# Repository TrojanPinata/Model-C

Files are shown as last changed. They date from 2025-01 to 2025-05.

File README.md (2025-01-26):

<div align="center">

# Model-C

### A four function calculator and numpad combo with integrated battery, power-saving, and mechanical switches

The first version of this project is stored in the `old pcb` directory, and is based off of the ATmega32A MCU. While good, I felt like the RP2040 is more realistic in terms of both cost and development overhead.

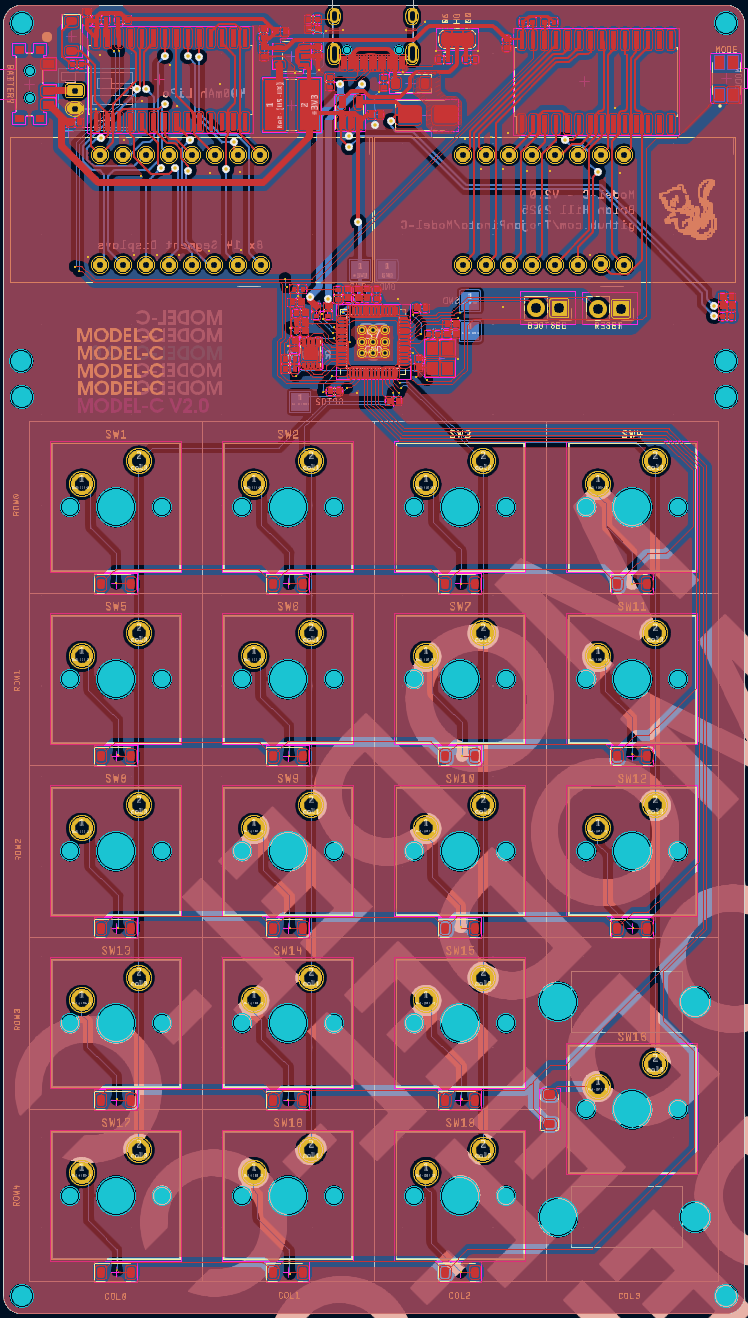
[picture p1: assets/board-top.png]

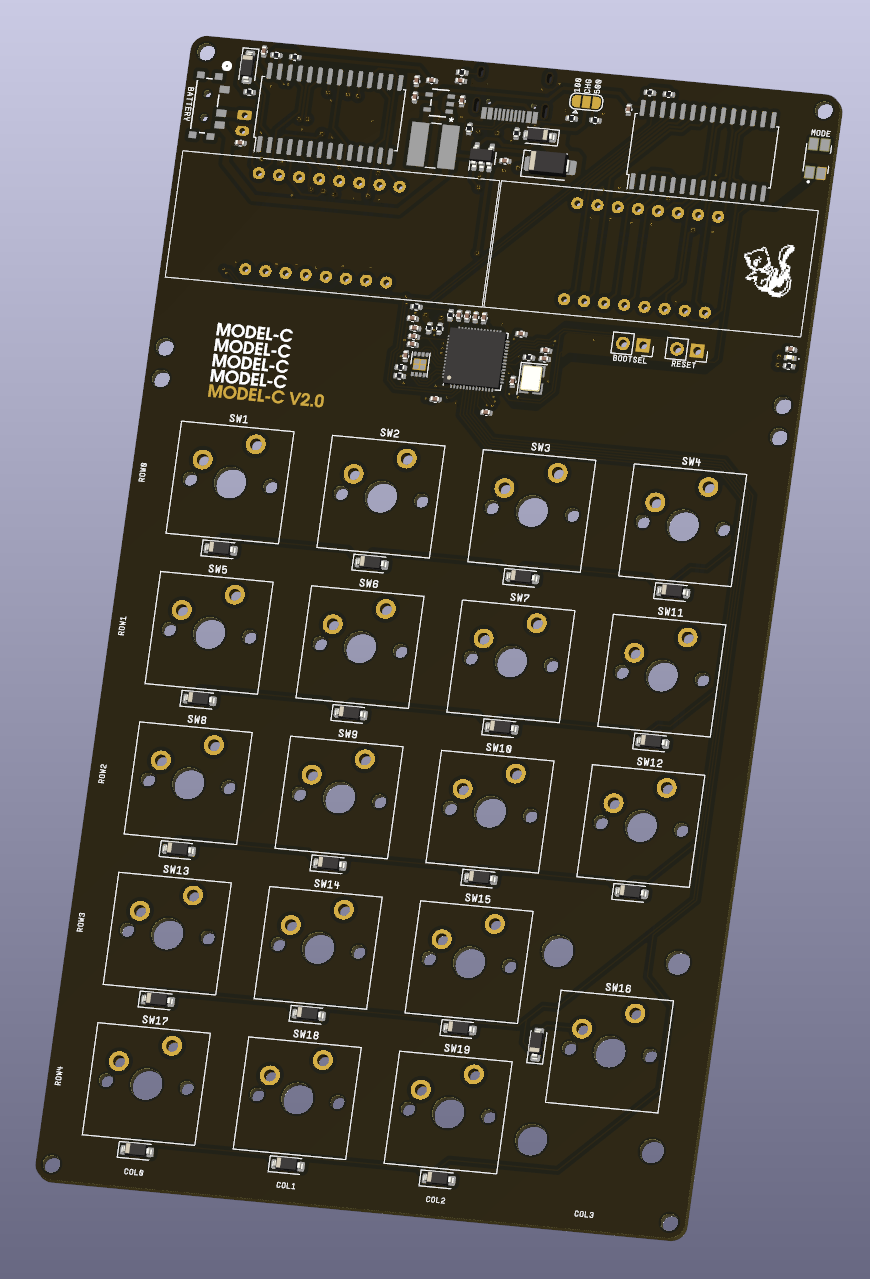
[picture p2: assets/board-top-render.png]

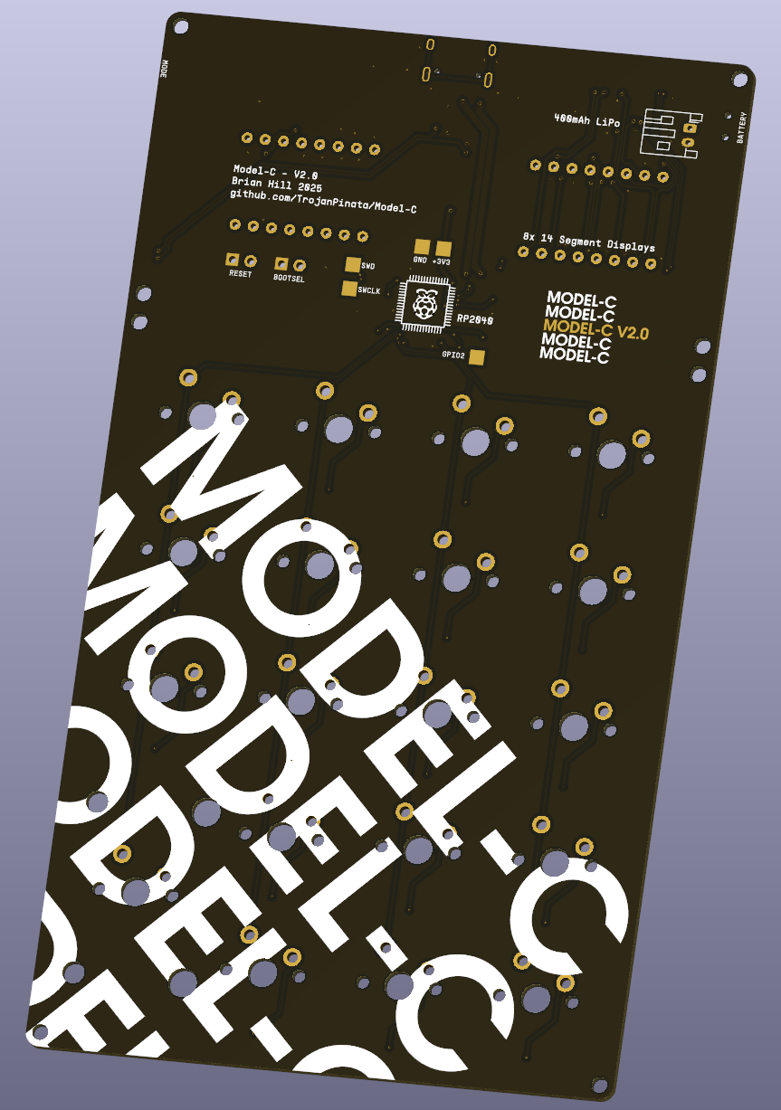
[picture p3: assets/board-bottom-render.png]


</div>

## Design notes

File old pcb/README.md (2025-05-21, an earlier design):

# Why does this exist?

I am leaving this design here because I think it is a good representation of where I started from and what I am capable now.

This project has been refined and I feel the current design is much more cost efficient and useful.

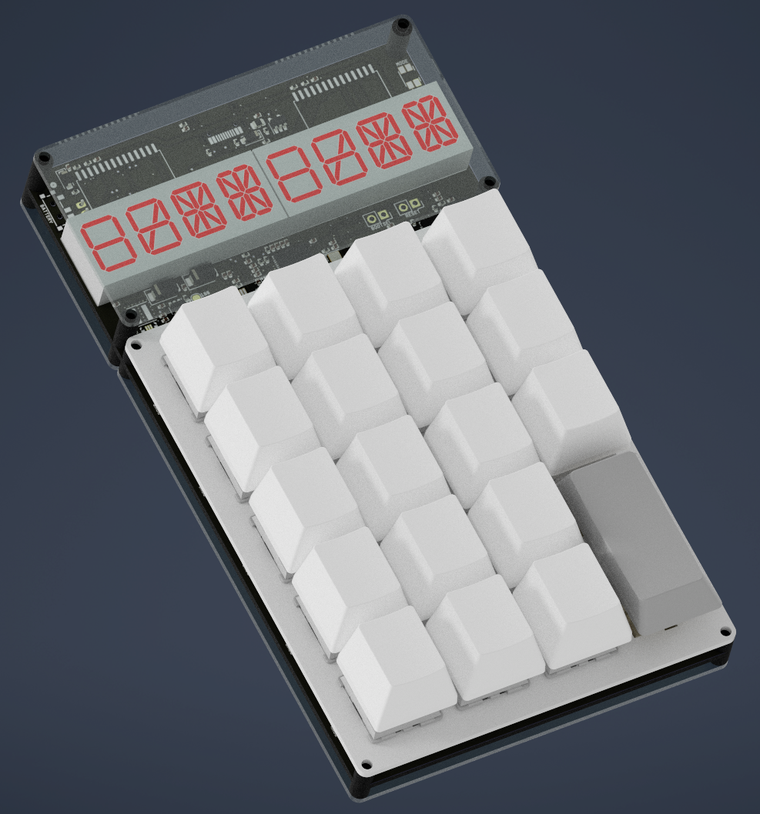
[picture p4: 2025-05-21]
case/renders/c1.png

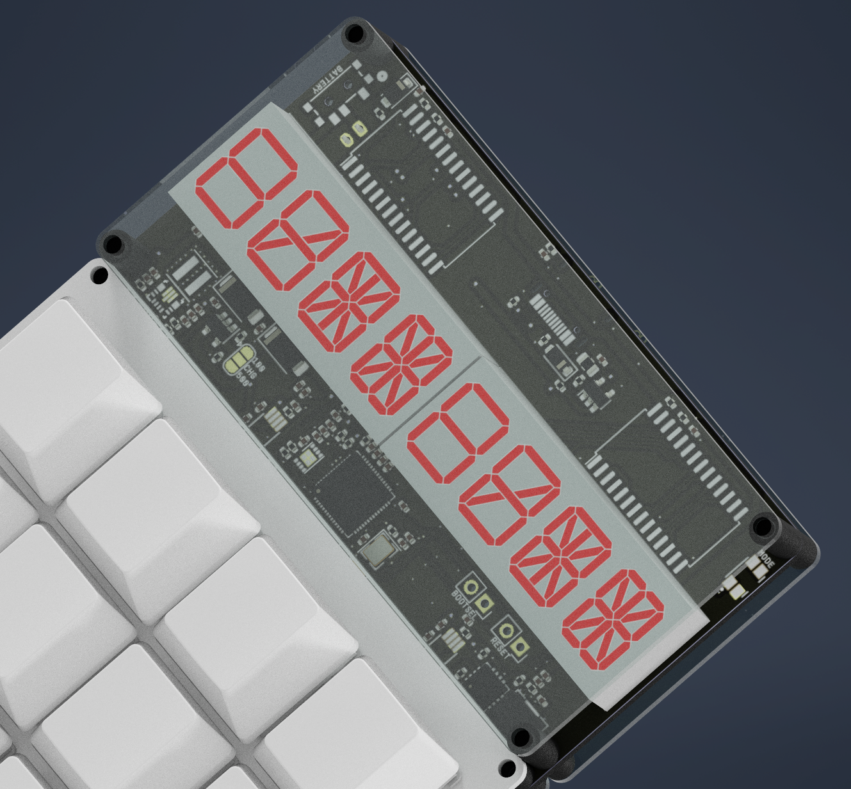
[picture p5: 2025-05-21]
case/renders/c3.png

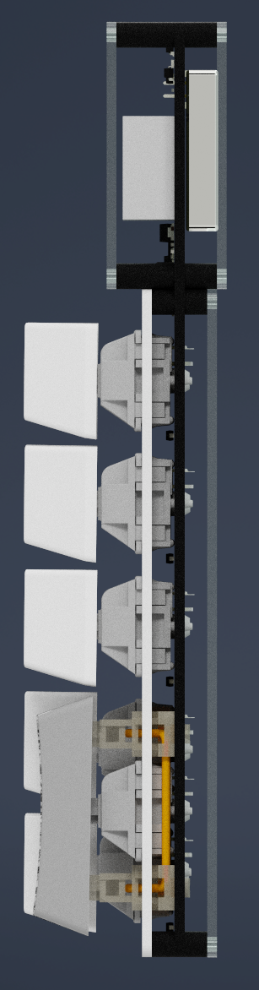
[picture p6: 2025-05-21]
case/renders/c2.png

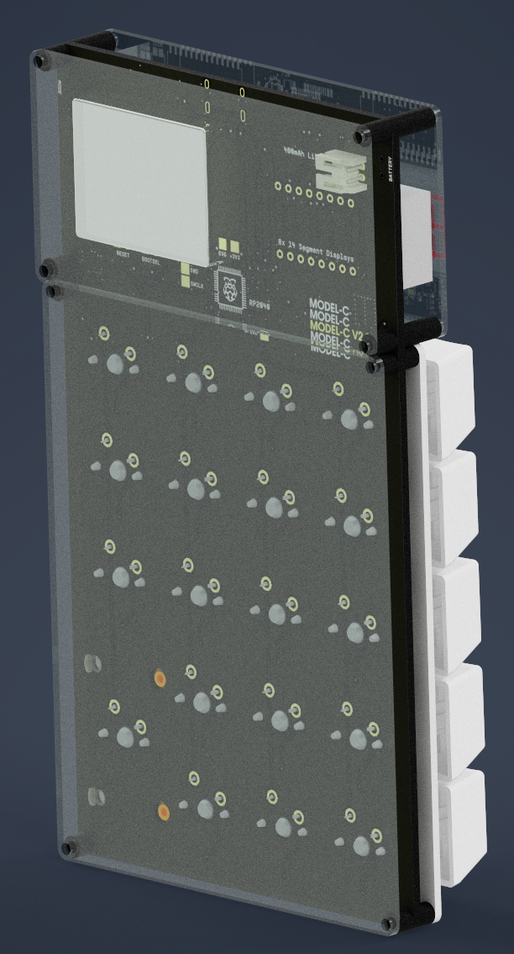
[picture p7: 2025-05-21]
case/renders/c4.png

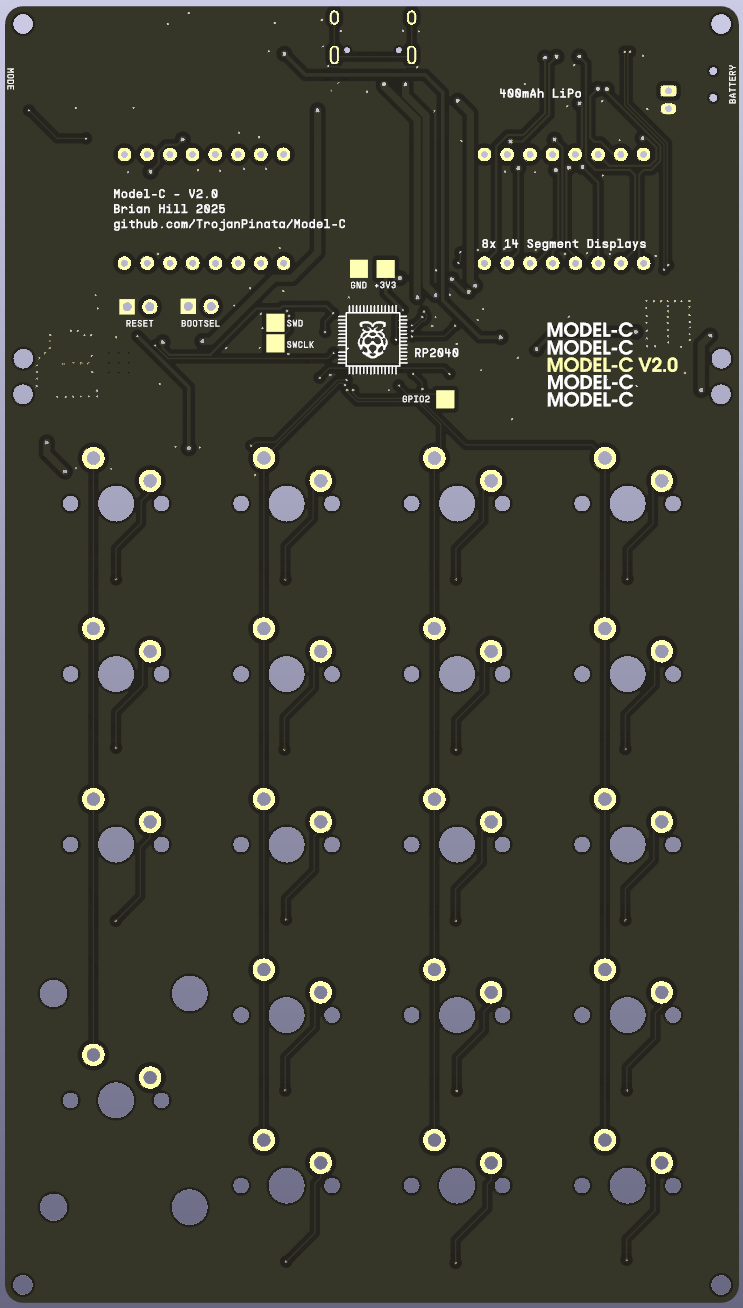
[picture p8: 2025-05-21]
case/back.png

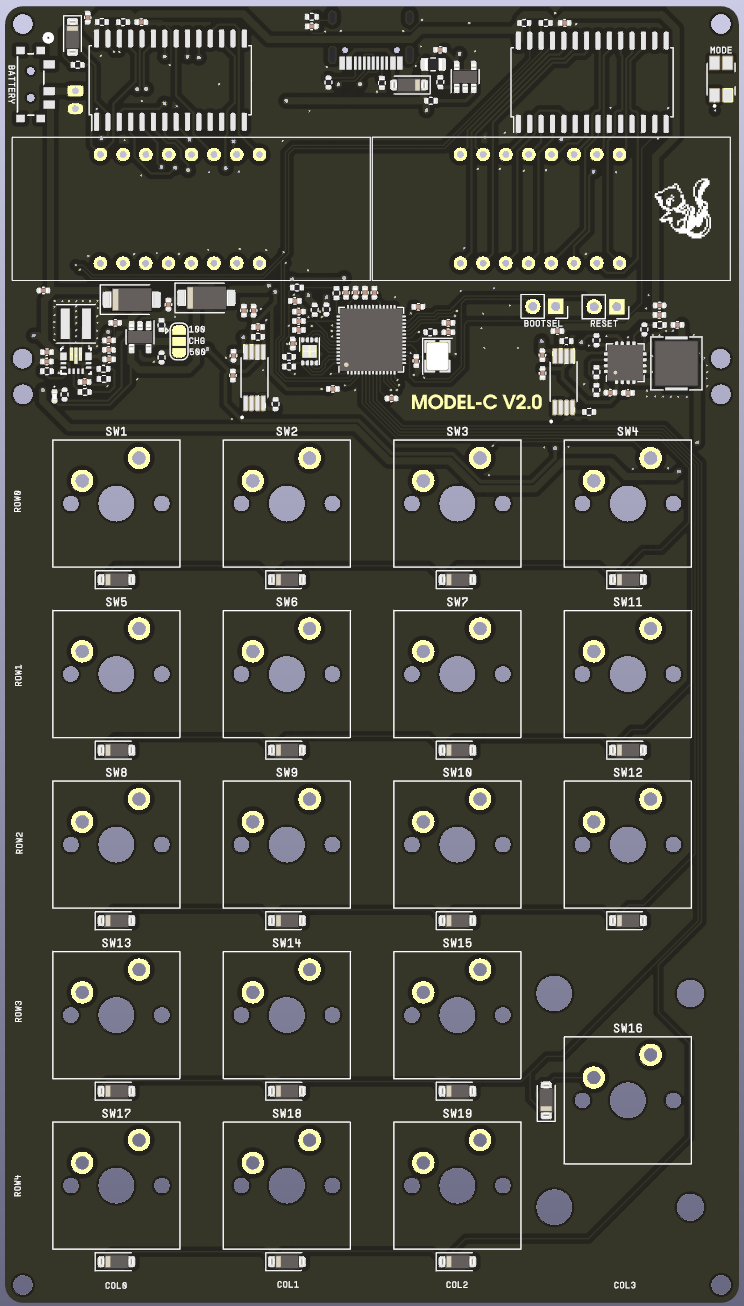
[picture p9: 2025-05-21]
case/front.png

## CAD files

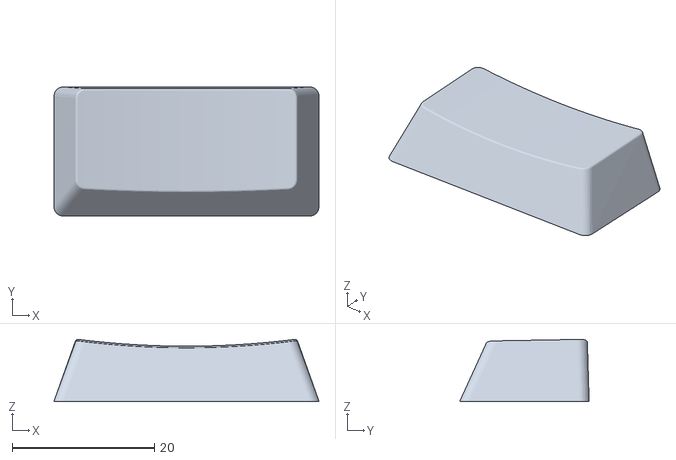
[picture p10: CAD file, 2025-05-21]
case/references/POS_2u_Cherry_row1.stl
37.2 x 18.2 x 8.72

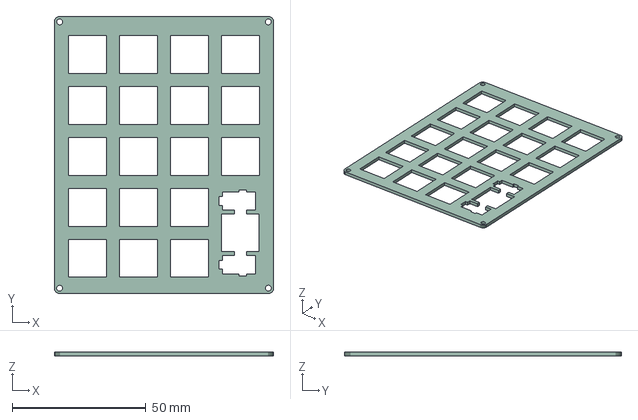
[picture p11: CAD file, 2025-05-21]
case/switchplate/switchplate.step
82.0 x 103.5 x 1.50 mm

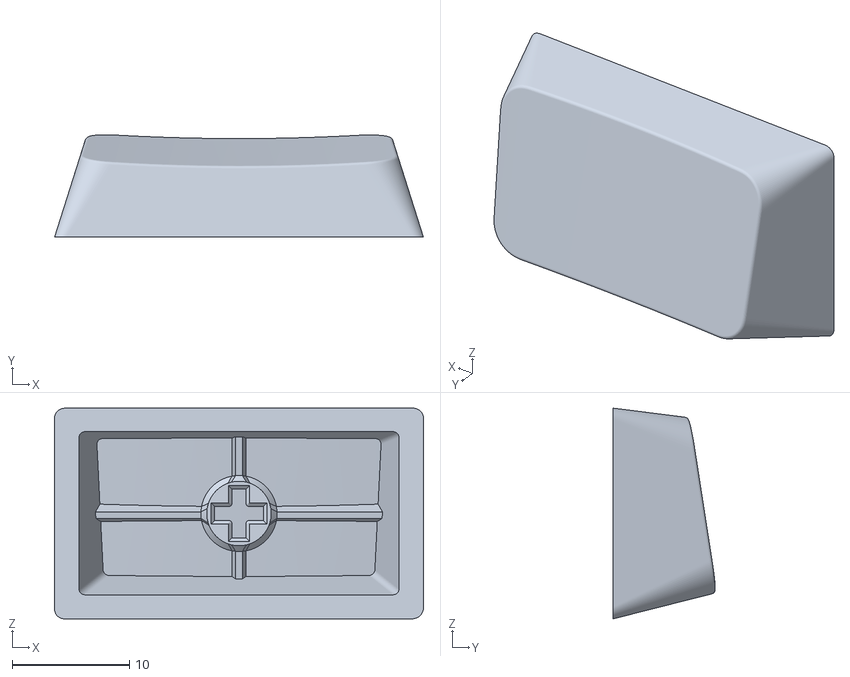
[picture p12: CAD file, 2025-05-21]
case/references/Cherry_R1_1.75u.stl
31.5 x 8.74 x 18.0

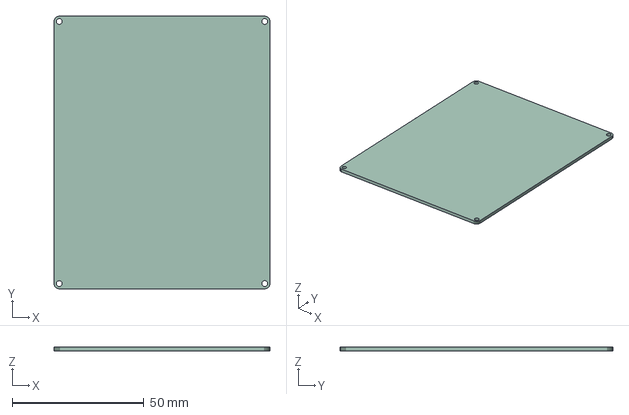
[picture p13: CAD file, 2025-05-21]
case/switchplate/backplate.step
82.0 x 103.5 x 1.50 mm

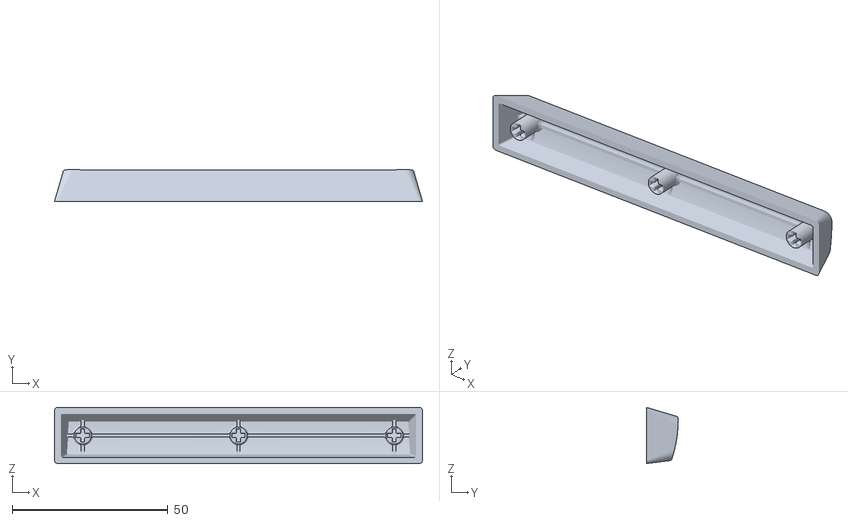
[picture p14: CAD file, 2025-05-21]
case/references/Cherry_Spacebar_6.25u.stl
118.1 x 10.1 x 18.0

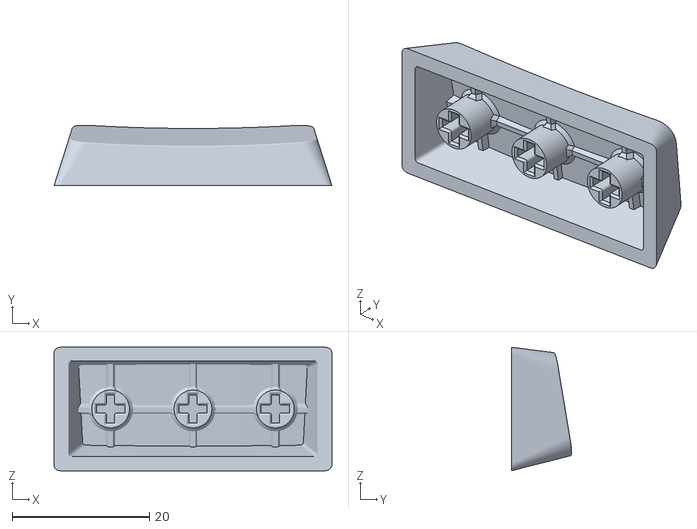
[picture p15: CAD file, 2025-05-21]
case/references/Cherry_R1_2.25u.stl
40.5 x 8.81 x 18.0

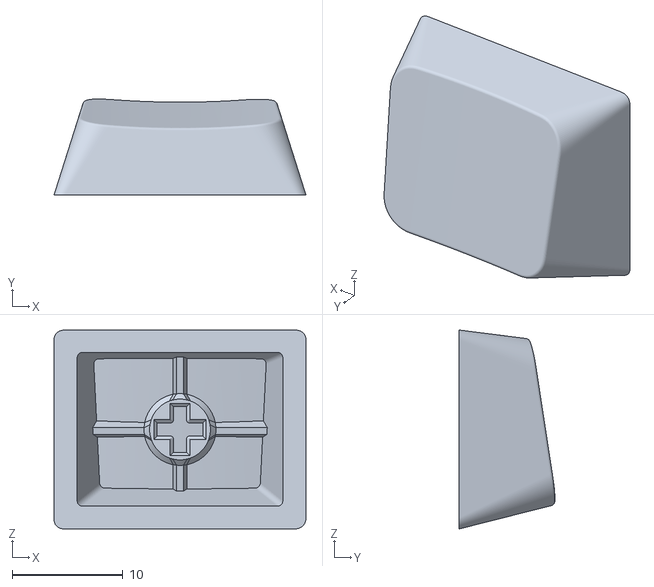
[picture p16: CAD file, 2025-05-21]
case/references/Cherry_R1_1.5u.stl
22.8 x 8.68 x 18.0

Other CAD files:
case/14seg_surrogate.ipt
case/OldVersions/Assembly2.0001.iam
case/OldVersions/backplate.0001.ipt
case/OldVersions/battery_cover.0001.ipt
case/OldVersions/battery_spacer.0001.ipt
case/OldVersions/black_screen.0001.ipt
case/OldVersions/model-c.0002.ipt
case/OldVersions/model-c_full.0009.iam
case/OldVersions/screen_spacer.0001.ipt
case/OldVersions/switchplate.0001.ipt
case/OldVersions/switchplate_spacer.0001.ipt
case/backplate.ipt
case/battery_cover.ipt
case/battery_spacer.ipt
case/battery_surrogate.ipt
case/black_screen.ipt
case/model-c.ipt
case/model-c_full.iam
case/references/2U Stabilizer.ipt
case/references/6.25U Stabilizer.ipt
case/references/Cherry_R1_1.5u.ipt
case/references/Cherry_R1_1.75u.ipt
case/references/Cherry_R1_2.25u.ipt
case/references/Cherry_Spacebar_6.25u.ipt
case/references/Kailh Hotswap MX v22.ipt
case/references/OLED.ipt
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

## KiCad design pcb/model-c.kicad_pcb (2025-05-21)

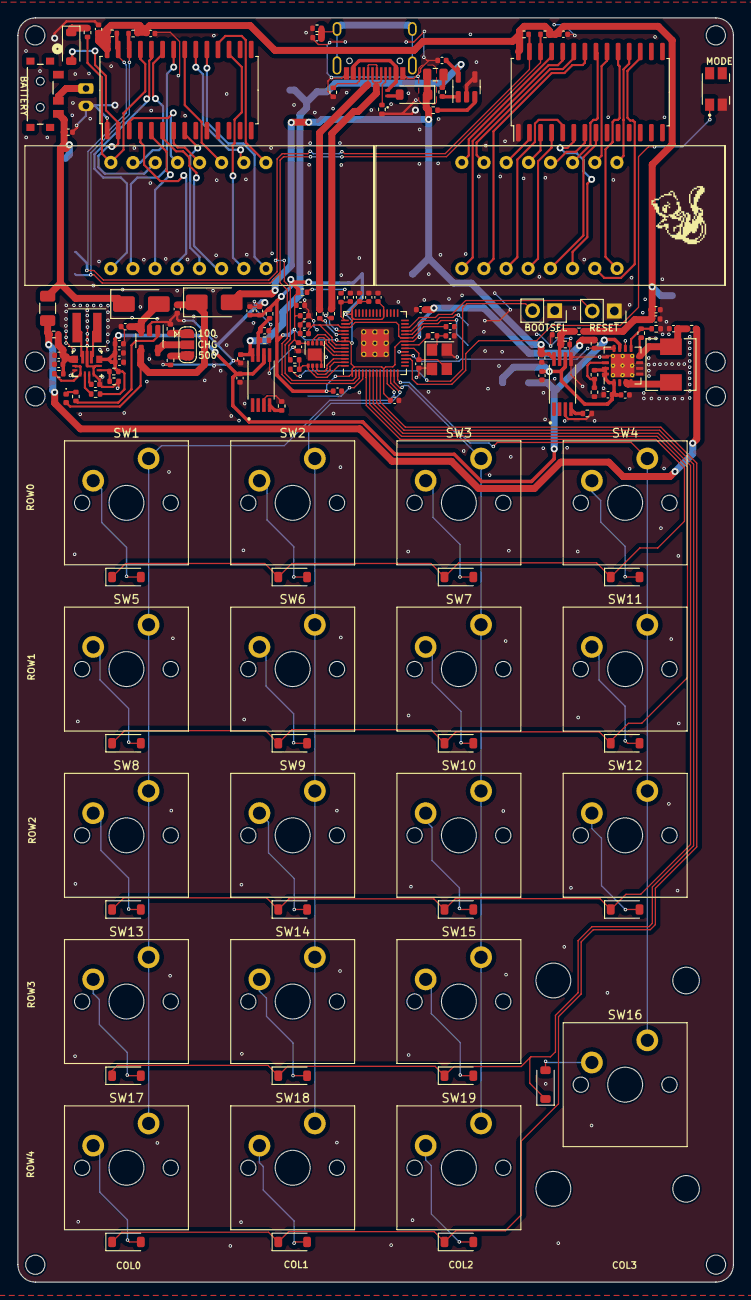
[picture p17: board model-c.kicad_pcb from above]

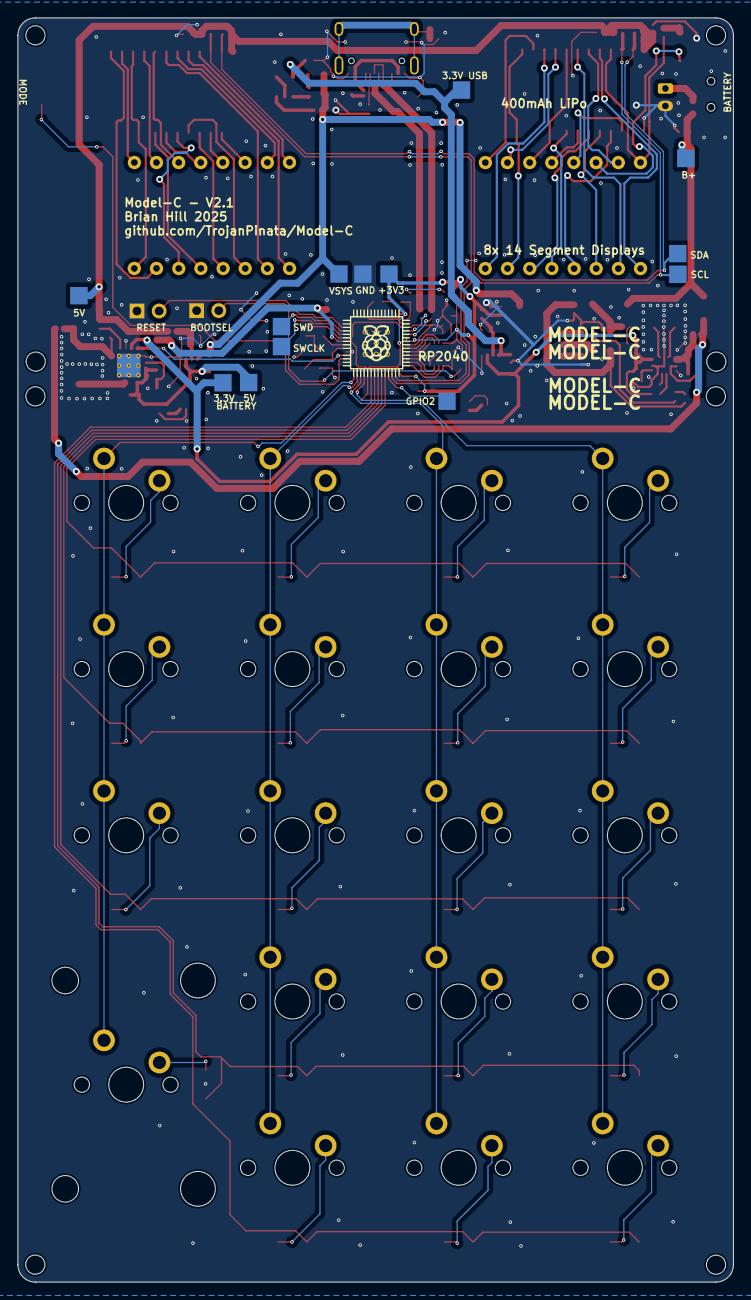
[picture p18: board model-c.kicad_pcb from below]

Board: 2 copper layers, 82.0 x 144.9 mm, 161 parts (14 on the bottom side), 126 nets.

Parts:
C1, C5, C6, C8, C9, C11, C12, C13, C14, C15, C16, C17, C24, C30, C31, C32, C33: 0.1uF; C_0402_1005Metric
C2, C21, C23, C25, C26, C29, C34, C37, C39, C40, C41: 10uF; C_0402_1005Metric
C3, C4: 22pF; C_0402_1005Metric
C7, C42: 1uF; C_0402_1005Metric
C10, C18: 2.2uF; C_0402_1005Metric
C19, C20, C22: 4.7uF; C_0402_1005Metric
C27, C35, C36: 22uF; C_0402_1005Metric
C28: 100uF_LowESR; C_0402_1005Metric
C38: 100nF; C_0402_1005Metric
D1, D2, D3, D4, D5, D6, D7, D8, D9, D10, D11, D12, D13, D14, D15, D16, D17, D18, D19: D; D_SOD-123
D20: 1N4148; D_SOD-123
D21: 1N4002W; D_SOD-123
D22: MBRA140; D_SMA
D23: LED; LED_0402_1005Metric
D24: SS14; D_SMA
D25: TPD1E05U06; RTVS_DFN1006-2_SOD882_NEX
F1: 0805L050WR; Fuse_0805_2012Metric
F2: Polyfuse_Small; Fuse_1206_3216Metric
FB1, FB2, FB3, FB4, FB5: FB; R_0402_1005Metric
H1: Stabilizer; Stabilizer_Cherry_MX_2.00u
IC1, IC2: HTK16K33; SOP-28_7.5x17.9mm_P1.27mm
J1: Batt; JST_PH_S2B-PH-K_1x02_P2.00mm_Horizontal
J2, J3: Conn_01x02_Socket; PinSocket_1x02_P2.54mm_Vertical
JP2: 500mA - 100mA; SolderJumper-3_P1.3mm_Open_RoundedPad1.0x1.5mm
L1: 4.7uH; L_Sunlord_MWSA0503S
L2: 1.5uH; L_Coilcraft_XxL4020
R1, R3: 1k; R_0402_1005Metric
R2, R8, R16, R17, R18, R21, R23: 10k; R_0402_1005Metric
R4: 47k; R_0402_1005Metric
R5: 160k; R_0402_1005Metric
R6, R7: 5.1k; R_0402_1005Metric
R9, R22, R26, R27, R28, R30, R32: 100k; R_0402_1005Metric
R10: 200; R_0402_1005Metric
R11: 1; R_0402_1005Metric
R12, R13: 27; R_0402_1005Metric
R14: 330; R_0402_1005Metric
R15: 2k; R_0402_1005Metric
R19, R20, R24, R25: 4.7k; R_0402_1005Metric
R29: 316k; R_0402_1005Metric
R31: 523k; R_0402_1005Metric
S1: MODE; SW_EVQ-P7A01P
SW1, SW2, SW3, SW4, SW5, SW6, SW7, SW8, SW9, SW10, SW11, SW12, SW13, SW14, SW15, SW17, SW18, SW19: SW_SPST; SW_Cherry_MX_PCB_1.00u
SW16: SW_SPST; SW_Cherry_MX_PCB_2.00u_90deg
SW21: SW_SPDT; MK-12C02-G020_GSW
TP1, TP2, TP3, TP4, TP5, TP6, TP7, TP8, TP9, TP10, TP11, TP12, TP13: TestPoint; CustomTestPoint
U1: W25Q16JVUXIQ; SON-8-1EP_3x2mm_P0.5mm_EP1.4x1.6mm
U2, U6: 14seg; 14 seg
U3: RP2040; RP2040-QFN-56
U4: MCP73831-2-OT; SOT-23-5
U5: TPS61090; Texas_S-PVQFN-N16_EP2.7x2.7mm_ThermalVias
U7: TLV75533PDBVR; SOT-23-5
U8, U9: TPS2115APW; SOP65P640X120-8N
U11: TPS63070RNMR; RNM0015A
USB1: HRO-TYPE-C-31-M-12
Y1: 12MHz; Crystal_SMD_3225-4Pin_3.2x2.5mm

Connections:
+1V1: C7.1, C8.1, C9.1, U3.23 (DVDD), U3.45 (VREG_VOUT), U3.50 (DVDD)
+3V3: C1.2, C2.1, C11.1, C12.1, C13.1, C14.1, C15.1, C16.1, C17.1, C18.1, C22.1, FB3.1, R2.2, R10.1, R21.1, TP9.1, U1.8 (VCC), U3.1 (IOVDD), U3.10 (IOVDD), U3.22 (IOVDD), U3.33 (IOVDD), U3.42 (IOVDD), U3.44 (VREG_IN), U3.48 (USB_VDD), U3.49 (IOVDD)
+5V: C5.1, C21.1, C23.1, C24.1, C25.1, FB2.1, IC1.28 (VDD), IC2.28 (VDD), R17.2, R18.1, R19.2, R20.1, TP11.1
/3.3V_BATT: C30.1, C39.2, C40.1, C41.2, R28.1, R29.1, TP10.1, U5.11 (EN), U8.6 (1N2), U11.7 (VOUT), U11.8 (VOUT)
/3.3V_USB: C29.1, C31.1, TP7.1, U7.5 (OUT), U8.8 (1N1)
/5V_BATT: C27.1, C28.1, C33.1, R31.2, TP8.1, U5.1 (VOUT), U5.15 (VOUT), U5.16 (VOUT), U9.6 (1N2)
/ADC_VREF: R10.2, R11.1
/B+: F2.2, FB4.2, FB5.2
/LBO: R21.2, U3.18 (GPIO15), U5.12 (LBO)
/QSPI_SCLK: U1.6 (CLK), U3.52 (QSPI_SCLK)
/QSPI_SD0: U1.5 (DI(IO0)), U3.53 (QSPI_SD0)
/QSPI_SD1: U1.2 (DO(IO1)), U3.55 (QSPI_SD1)
/QSPI_SD2: U1.3 (IO2), U3.54 (QSPI_SD2)
/QSPI_SD3: U1.7 (IO3), U3.51 (QSPI_SD3)
/QSPI_SS: R1.1, R2.1, U1.1 (~CS), U3.56 (QSPI_SS)
/RUN: J3.2, U3.26 (RUN)
/SCL: IC1.26 (SCL), IC2.26 (SCL), R18.2, R20.2, TP12.1, U3.3 (GPIO1)
/SDA: IC1.27 (SDA), IC2.27 (SDA), R17.1, R19.1, TP13.1, U3.2 (GPIO0)
/USB_BOOT: J2.2, R1.2
/USB_DN: R13.2, USB1.5 (DN2), USB1.7 (DN1)
/USB_DP: R12.2, USB1.6 (DP1), USB1.8 (DP2)
/XIN: C3.2, U3.20 (XIN), Y1.3
/XOUT: R3.2, U3.21 (XOUT)
/col0: SW1.2 (B), SW5.2 (B), SW8.2 (B), SW13.2 (B), SW17.2 (B), U3.11 (GPIO8)
/col1: SW2.2 (B), SW6.2 (B), SW9.2 (B), SW14.2 (B), SW18.2 (B), U3.12 (GPIO9)
/col2: SW3.2 (B), SW7.2 (B), SW10.2 (B), SW15.2 (B), SW19.2 (B), U3.13 (GPIO10)
/col3: SW4.2 (B), SW11.2 (B), SW12.2 (B), SW16.2 (B), U3.14 (GPIO11)
/mode: S1.1_1, U3.17 (GPIO14)
/row0: D1.1 (K), D2.1 (K), D3.1 (K), D4.1 (K), U3.5 (GPIO3)
/row1: D5.1 (K), D6.1 (K), D7.1 (K), D8.1 (K), U3.6 (GPIO4)
/row2: D9.1 (K), D10.1 (K), D11.1 (K), D12.1 (K), U3.7 (GPIO5)
/row3: D13.1 (K), D14.1 (K), D15.1 (K), D16.1 (K), U3.8 (GPIO6)
/row4: D17.1 (K), D18.1 (K), D19.1 (K), U3.9 (GPIO7)
GND: C1.1, C2.2, C3.1, C4.2, C5.2, C6.2, C7.2, C8.2, C9.2, C10.2, C11.2, C12.2, C13.2, C14.2, C15.2, C16.2, C17.2, C18.2, C19.2, C20.2, C21.2, C22.2, C23.2, C24.2, C25.2, C26.2, C27.2, C28.2, C29.2, C30.2, C31.2, C32.2, C33.2, C34.2, C35.2, C36.2, C37.1, C38.2, C39.1, C40.2, C41.1, C42.2, IC1.1 (VSS), IC2.1 (VSS), J1.2, J2.1, J3.1, R6.2, R7.2, R8.1, R9.2, R15.1, R16.1, R24.2, R25.2, R26.2, R27.2, R30.2, R32.1, S1.2_1, TP3.1, U1.4 (GND), U1.9 (EP), U3.19 (TESTEN), U3.57 (GND), U4.2 (V_{SS}), U5.5 (PGND), U5.6 (PGND), U5.7 (PGND), U5.10 (SYNC), U5.13 (GND), U5.17 (PAD), U7.2 (GND), U7.4 (BP), U8.3 (D1), U8.5 (GND), U9.3 (D1), U9.5 (GND), U11.4 (GND), U11.6 (FB2), U11.10 (PGND), U11.15 (VSEL), USB1.1 (GND), USB1.12 (GND), Y1.2, Y1.4
unnamed: C4.1, R3.1, Y1.1
unnamed: C34.1, C37.2, FB5.1, R23.1, U11.12 (VIN), U11.13 (VIN)
unnamed: D1.2 (A), SW1.1 (A)
unnamed: D2.2 (A), SW2.1 (A)
unnamed: D3.2 (A), SW3.1 (A)
unnamed: D4.2 (A), SW4.1 (A)
unnamed: D5.2 (A), SW5.1 (A)
unnamed: D6.2 (A), SW6.1 (A)
unnamed: D7.2 (A), SW7.1 (A)
unnamed: D8.2 (A), SW11.1 (A)
unnamed: D9.2 (A), SW8.1 (A)
unnamed: D10.2 (A), SW9.1 (A)
unnamed: D11.2 (A), SW10.1 (A)
unnamed: D12.2 (A), SW12.1 (A)
unnamed: D13.2 (A), SW13.1 (A)
unnamed: D14.2 (A), SW14.1 (A)
unnamed: D15.2 (A), SW15.1 (A)
unnamed: D16.2 (A), SW16.1 (A)
unnamed: D17.2 (A), SW17.1 (A)
unnamed: D18.2 (A), SW18.1 (A)
unnamed: D19.2 (A), SW19.1 (A)
unnamed: D20.2 (A), IC2.2 (COM0/AD), U6.14 (COM0)
unnamed: D20.1 (K), R4.2
unnamed: D21.2 (A), D25.1 (K)
unnamed: C19.1, D22.1 (K), D23.2 (A), U4.4 (V_{DD})
unnamed: D23.1 (K), R14.1
unnamed: C42.1, D24.2 (A), U4.3 (V_{BAT})
unnamed: C20.1, D24.1 (K), F2.1, SW21.3 (C), TP5.1
unnamed: F1.2, FB1.2
unnamed: IC1.2 (COM0/AD), U2.14 (COM0)
unnamed: IC1.3 (COM1/KS0), U2.13 (COM1)
unnamed: IC1.4 (COM2/KS1), U2.4 (COM2)
unnamed: IC1.5 (COM3/KS2), U2.3 (COM3)
unnamed: IC1.6 (COM4), U2.6 (COM4)
unnamed: IC1.7 (COM5), U2.12 (COM5)
unnamed: IC1.8 (COM6), U2.5 (COM6)
unnamed: IC1.25 (ROW0/A2), U2.16 (D1_High)
unnamed: IC1.24 (ROW1/A1), U2.1 (D1_Low)
unnamed: IC1.23 (ROW2/A0), U2.15 (D2_High)
unnamed: IC1.22 (ROW3/K1), U2.2 (D2_Low)
unnamed: IC1.21 (ROW4/K2), U2.11 (D3_High)
unnamed: IC1.20 (ROW5/K3), U2.10 (D3_Low)
unnamed: IC1.19 (ROW6/K4), U2.8 (D4_High)
unnamed: IC1.18 (ROW7/K5), U2.9 (D4_Low)
unnamed: IC1.17 (ROW8/K6), U2.7 (DP)
unnamed: IC2.3 (COM1/KS0), U6.13 (COM1)
unnamed: IC2.4 (COM2/KS1), U6.4 (COM2)
unnamed: IC2.5 (COM3/KS2), U6.3 (COM3)
unnamed: IC2.6 (COM4), U6.6 (COM4)
unnamed: IC2.7 (COM5), U6.12 (COM5)
unnamed: IC2.8 (COM6), U6.5 (COM6)
unnamed: IC2.25 (ROW0/A2), R4.1, U6.16 (D1_High)
unnamed: IC2.24 (ROW1/A1), U6.1 (D1_Low)
unnamed: IC2.23 (ROW2/A0), U6.15 (D2_High)
unnamed: IC2.22 (ROW3/K1), U6.2 (D2_Low)
unnamed: IC2.21 (ROW4/K2), U6.11 (D3_High)
unnamed: IC2.20 (ROW5/K3), U6.10 (D3_Low)
unnamed: IC2.19 (ROW6/K4), U6.8 (D4_High)
unnamed: IC2.18 (ROW7/K5), U6.9 (D4_Low)
unnamed: IC2.17 (ROW8/K6), U6.7 (DP)
unnamed: J1.1, SW21.2 (B)
unnamed: JP2.1 (A), R16.2
unnamed: JP2.3 (B), R15.2
unnamed: JP2.2 (C), U4.5 (PROG)
unnamed: L1.2, U5.3 (SW), U5.4 (SW)
unnamed: C10.1, R11.2, U3.43 (ADC_AVDD)
unnamed: TP4.1, U3.4 (GPIO2)
unnamed: TP1.1, U3.24 (SWCLK)
unnamed: TP2.1, U3.25 (SWD)
unnamed: R13.1, U3.46 (USB_DM)
unnamed: R12.1, U3.47 (USB_DP)
unnamed: R14.2, U4.1 (STAT)
unnamed: R31.1, R32.2, U5.14 (FB)
unnamed: R5.2, R9.1, U5.9 (LBI)
unnamed: C26.1, FB4.1, L1.1, R5.1, U5.8 (VBAT)
unnamed: R22.2, U7.3 (EN)
unnamed: FB1.1, U7.1 (IN)
unnamed: R25.1, U8.4 (ILIM)
unnamed: C35.1, FB3.2, R26.1, U8.7 (OUT)
unnamed: R24.1, U9.4 (ILIM)
unnamed: C36.1, FB2.2, R27.1, U9.7 (OUT)
unnamed: R23.2, U11.1 (PS_SYNC), U11.14 (EN)
unnamed: R29.2, R30.1, U11.5 (FB)
unnamed: L2.1, U11.11 (L1)
unnamed: L2.2, U11.9 (L2)
unnamed: R28.2, U11.2 (PG)
unnamed: C38.1, U11.3 (VAUX)
unnamed: R6.1, USB1.4 (CC1)
unnamed: R7.1, USB1.10 (CC2)
unnamed: C6.1, R8.2, USB1.13 (SHIELD)
VBUS: D25.2 (A), USB1.2 (VBUS), USB1.11 (VBUS)
VSYS: C32.1, D21.1 (K), D22.2 (A), F1.1, R22.1, TP6.1, U9.8 (1N1)

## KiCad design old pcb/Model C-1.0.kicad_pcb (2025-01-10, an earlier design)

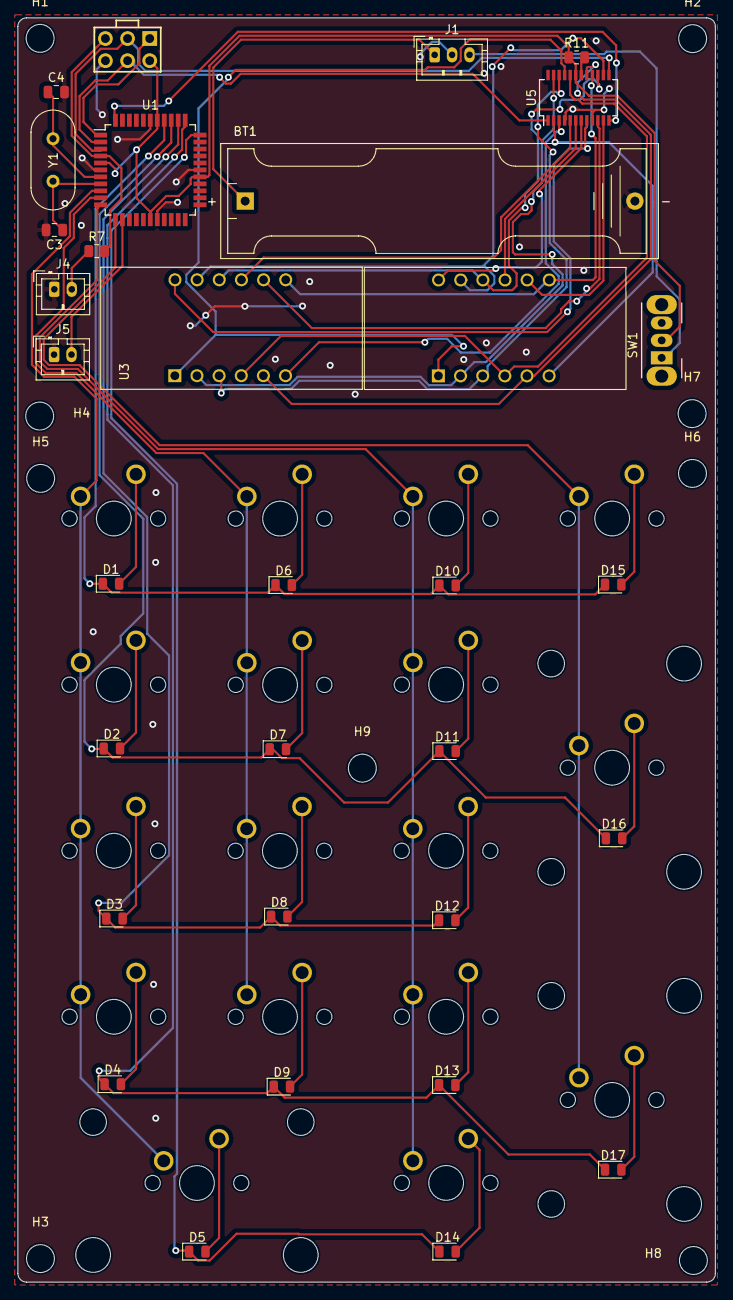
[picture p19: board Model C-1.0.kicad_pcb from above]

Board: 2 copper layers, 80.0 x 145.0 mm, 58 parts (0 on the bottom side), 56 nets.

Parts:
BT1: Battery_Cell; BatteryHolder_Keystone_2466_1xAAA
C3, C4: 22p; C_0805_2012Metric
D1, D2, D3, D4, D5, D6, D7, D8, D9, D10, D11, D12, D13, D14, D15, D16, D17: D; D_0805_2012Metric
H1, H2, H3, H4, H5, H6, H7, H8, H9: MountingHole; MountingHole_3.2mm_M3
J1: 1.5V-5V Boost Converter; JST_PH_B3B-PH-K_1x03_P2.00mm_Vertical
J3: AVR-ISP-6; AVR_ICSP_3x2
J4: reset; JST_PH_B2B-PH-K_1x02_P2.00mm_Vertical
J5: boot; JST_PH_B2B-PH-K_1x02_P2.00mm_Vertical
R7: 10k; R_0805_2012Metric
R11: 12k; R_0805_2012Metric
SW1: SW_SPST; SW_CuK_OS102011MA1QN1_SPDT_Angled
SW-1U-1, SW-1U-2, SW-1U-3, SW-1U-4, SW-1U-5, SW-1U-6, SW-1U-7, SW-1U-8, SW-1U-9, SW-1U-10, SW-1U-11, SW-1U-12, SW-1U-13, SW-1U-14: KEYSW; MXOnly-1U-NoLED
SW-2U-1: KEYSW; MXOnly-2U-NoLED
SW-2U-2, SW-2U-3: KEYSW; MXOnly-2U-VerticalStabilizers-NoLED
U1: ATmega32A-A; TQFP-44_10x10mm_P0.8mm
U3, U4: CA56-12CGKWA
U5: MAX7219; SSOP-24_3.9x8.7mm_P0.635mm
Y1: Crystal; Crystal_HC49-4H_Vertical

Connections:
+5V: J1.3, SW1.1 (A)
/0: U4.6 (CA4), U5.2 (DIG_0)
/1: U4.8 (CA3), U5.11 (DIG_1)
/2: U4.9 (CA2), U5.6 (DIG_2)
/3: U4.12 (CA1), U5.7 (DIG_3)
/4: U3.6 (CA4), U5.3 (DIG_4)
/5: U3.8 (CA3), U5.10 (DIG_5)
/5v switched: J3.2 (VCC), R11.1, SW1.2 (B), U1.5 (VCC), U1.17 (VCC), U1.27 (AVCC), U1.38 (VCC), U5.19 (V+)
/6: U3.9 (CA2), U5.5 (DIG_6)
/7: U3.12 (CA1), U5.8 (DIG_7)
/a: U3.11 (a), U4.11 (a), U5.14 (SEG_A)
/b: U3.7 (b), U4.7 (b), U5.16 (SEG_B)
/boot: J5.2, U1.13 (PD4)
/c: U3.4 (c), U4.4 (c), U5.20 (SEG_C)
/col0: SW-1U-1.1, SW-1U-2.1, SW-1U-3.1, SW-1U-4.1, SW-2U-1.1, U1.9 (PD0)
/col1: SW-1U-5.1, SW-1U-6.1, SW-1U-7.1, SW-1U-8.1, U1.10 (PD1)
/col2: SW-1U-9.1, SW-1U-10.1, SW-1U-11.1, SW-1U-12.1, SW-1U-13.1, U1.11 (PD2)
/col3: SW-1U-14.1, SW-2U-2.1, SW-2U-3.1, U1.12 (PD3)
/d: U3.2 (d), U4.2 (d), U5.23 (SEG_D)
/dp: U3.3 (DPX), U4.3 (DPX), U5.22 (SEG_DP)
/e: U3.1 (e), U4.1 (e), U5.21 (SEG_E)
/f: U3.10 (f), U4.10 (f), U5.15 (SEG_F)
/g: U3.5 (g), U4.5 (g), U5.17 (SEG_G)
/miso: J3.1 (MISO), U1.1 (PB5)
/mosi: J3.4 (MOSI), U1.2 (PB6), U5.1 (DIN)
/reset: J3.5 (~RST), R7.2, U1.4 (~RESET)
/row0: D1.1, D6.1, D10.1, D15.1, U1.37 (PA0)
/row1: D2.1, D7.1, D11.1, D16.1, U1.36 (PA1)
/row2: D3.1, D8.1, D12.1, U1.35 (PA2)
/row3: D4.1, D9.1, D13.1, D17.1, U1.34 (PA3)
/row4: D5.1, D14.1, U1.33 (PA4)
/sck: J3.3 (SCK), U1.3 (PB7), U5.13 (CLK)
/ssg: U1.44 (PB4), U5.12 (LOAD)
GND: BT1.2 (-), C3.2, C4.2, J1.2, J3.6 (GND), J4.1, J5.1, U1.6 (GND), U1.18 (GND), U1.28 (GND), U1.39 (GND), U5.4 (GND), U5.9 (GND)
unnamed: BT1.1 (+), J1.1
unnamed: D1.2, SW-1U-1.2
unnamed: D2.2, SW-1U-2.2
unnamed: D3.2, SW-1U-3.2
unnamed: D4.2, SW-1U-4.2
unnamed: D5.2, SW-2U-1.2
unnamed: D6.2, SW-1U-5.2
unnamed: D7.2, SW-1U-6.2
unnamed: D8.2, SW-1U-7.2
unnamed: D9.2, SW-1U-8.2
unnamed: D10.2, SW-1U-9.2
unnamed: D11.2, SW-1U-10.2
unnamed: D12.2, SW-1U-11.2
unnamed: D13.2, SW-1U-12.2
unnamed: D14.2, SW-1U-13.2
unnamed: D15.2, SW-1U-14.2
unnamed: D16.2, SW-2U-2.2
unnamed: D17.2, SW-2U-3.2
unnamed: J4.2, R7.1
unnamed: C3.1, U1.8 (XTAL1), Y1.1
unnamed: C4.1, U1.7 (XTAL2), Y1.2
unnamed: R11.2, U5.18 (ISET)

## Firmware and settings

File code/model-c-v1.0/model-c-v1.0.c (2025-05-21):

#include <stdio.h>
#include "pico/stdlib.h"
#include "hardware/i2c.h"
#include "hardware/timer.h"
#include "hardware/clocks.h"
#include "hardware/uart.h"

#include "keycodes.h"
#include "calculator.h"


// states
#define START 0
#define NUMPAD 1
#define CALC 2
#define ERROR 3
uint8_t state = START;

// display setup
#define I2C_PORT i2c0
#define I2C_SDA 0
#define I2C_SCL 1
#define I2C_TOGGLE 0

// mode switch
#define MODE_PIN 14

// matrix and key setup
#define ROWS 5
#define COLS 4
#define DEBOUNCE 20000  // 50 ms delay
#define CONFIRM 3   // number of consecutive reads the key was confirmed for
#define HID_DELAY 5 // ms delay between checking/sending next keypress

const uint8_t row_pins[ROWS] = {3, 4, 5, 6, 7};
const uint8_t col_pins[COLS] = {8, 9, 10, 11};

uint64_t last_keypress_time[ROWS] = {0};

volatile bool key_pressed = false;
uint8_t keys_pressed[6] = {0};
uint8_t prev_state[6] = {0}; // state array for switches 
// Oh? You wanted NKRO? Tell me how you are planning to fit 6 of your greasy fingers on a numpad thats smaller than your hand.
// This isn't a gaming keyboard or something where theres any benefit at all. You must have thought I would take the time to
// make a custom descriptor before. Suprise, I have - and this is not the project for that.

void scan_matrix_irq(int dir);
void scan_matrix(void);
void init_matrix(void);

void keypress_callback(uint8_t gpio, uint32_t events) {
    uint64_t now = time_us_64();
    int index = 0;

    if (gpio == MODE_PIN) {
        irq_set_enabled(IO_IRQ_BANK0, false);
        state = (gpio_get(MODE_PIN) == 0) ? CALC : NUMPAD;
        init_matrix();
        irq_set_enabled(IO_IRQ_BANK0, true);
    }

    for (uint8_t i = 0; i < ROWS; i++) {
        if (row_pins[i] == gpio) {
            index = i;
        }
    }

    if (now - last_keypress_time[index] < DEBOUNCE) { return; }
    last_keypress_time[index] = now;

    if (events & GPIO_IRQ_EDGE_FALL) {
        scan_matrix_irq(GPIO_IRQ_EDGE_FALL);
    }
    if (events & GPIO_IRQ_EDGE_RISE) {
        scan_matrix_irq(GPIO_IRQ_EDGE_RISE);
    }
}

void keypress_handler(void) {
    printf("keypress handler\n");

    //irq_set_enabled(IO_IRQ_BANK0, false); // turn off interrputs

    for (uint8_t i = 0; i < ROWS; i++) {
        uint gpio = row_pins[i];
        uint32_t events = gpio_get_irq_event_mask(gpio);

        if (gpio_get_irq_event_mask(MODE_PIN)) {
            keypress_callback(MODE_PIN, gpio_get_irq_event_mask(MODE_PIN));
            break;
        }
        else if (events) {
            keypress_callback(gpio, events);
            //gpio_acknowledge_irq(row_pins[i], events);
        }
    }
}

void clear_IRQ_flags() {
    gpio_acknowledge_irq(MODE_PIN, gpio_get_irq_event_mask(MODE_PIN));
    for (uint8_t i = 0; i < ROWS; i++) {
        uint32_t events = gpio_get_irq_event_mask(row_pins[i]);
        if (events) {
            gpio_acknowledge_irq(row_pins[i], events);
        }
    }
}

void init_matrix() {
    // initialize rows as inputs pulled up
    for (uint8_t i = 0; i < ROWS; i++) {
        gpio_init(row_pins[i]);
        gpio_set_dir(row_pins[i], GPIO_IN);
        gpio_pull_up(row_pins[i]);  // make rows inputs being pulled up - when column set to low

        // setup callbacks for interrupt driven key handling
        if (state == CALC) {
            gpio_set_irq_enabled(row_pins[i], GPIO_IRQ_EDGE_FALL | GPIO_IRQ_EDGE_RISE, true);
        }
        else {
            gpio_set_irq_enabled(row_pins[i], GPIO_IRQ_EDGE_FALL | GPIO_IRQ_EDGE_RISE, false);
        }
    }

    irq_set_exclusive_handler(IO_IRQ_BANK0, keypress_handler);

    if (state == CALC) {
        // initialize columns as outputs which turn off when scanning each column - pulls row down to indicate hit
        // start all columns off in order to allow for interrupt when key hit - not polling here
        for (uint8_t i = 0; i < COLS; i++) {
            gpio_init(col_pins[i]);
            gpio_set_dir(col_pins[i], GPIO_OUT);
            gpio_put(col_pins[i], 0); 
        }
    }
    else {
        for (uint8_t i = 0; i < COLS; i++) {
            gpio_init(col_pins[i]);
            gpio_set_dir(col_pins[i], GPIO_OUT);
            gpio_put(col_pins[i], 1); 
        }
    }
    
    printf("matrix initialized\n");
    clear_IRQ_flags();
}

void init_state() {
    gpio_init(MODE_PIN);
    gpio_set_dir(MODE_PIN, GPIO_IN);
    gpio_pull_up(MODE_PIN);

    state = (gpio_get(MODE_PIN) == 0) ? CALC : NUMPAD;

    init_matrix();
    gpio_set_irq_enabled(MODE_PIN, GPIO_IRQ_EDGE_FALL | GPIO_IRQ_EDGE_RISE, true);

    printf("mode switch initialized\n");
}

void save_state() {
    for (uint8_t i = 0; i < 6; i++) {
        prev_state[i] = keys_pressed[i];
    }
}

void remove_duplicates(uint8_t keycode) {
    // check for duplicate additions
    bool check = false;
    for (uint8_t i = 0; i < 6; i++) {
        if (keys_pressed[i] == keycode && !check) {
            check = true;
        }
        else if (keys_pressed[i] == keycode && check) {
            keys_pressed[i] = 0;
        }
    }
}

// add key to array
void add_key(uint8_t keycode) {
    if (keycode == SIGN) {  // convert sign into something usable by a computer 
        keycode = MINUS;
    }
    
    for (uint8_t i = 0; i < 6; i++) {
        if (keys_pressed[i] == keycode) {
            return;
        }
    }
    for (uint8_t i = 0; i < 6; i++) {
        if (keys_pressed[i] == 0) {
            keys_pressed[i] = keycode;
            remove_duplicates(keycode);
            return;
        }
    }
}

// remove key from array
void remove_key(uint8_t keycode) {
    for (uint8_t i = 0; i < 6; i++) {
        if (keys_pressed[i] == keycode) {
            keys_pressed[i] = 0;
        }
    }

    // doing it again for insurance
    for (uint8_t i = 0; i < 6; i++) {
        if (keys_pressed[i] == keycode) {
            keys_pressed[i] = 0;
        }
    }
}

void scan_matrix_irq(int dir) {
    save_state();
    
    // set all columns to high in order to start scan and isolate key
    for (uint8_t i = 0; i < COLS; i++) {
        gpio_put(col_pins[i], 1); 
    }

    for (uint8_t col = 0; col < COLS; col++) {
        gpio_put(col_pins[col], 0);

        for (uint8_t row = 0; row < ROWS; row++) {
            if (gpio_get(row_pins[row]) == 0) {
                if (dir == GPIO_IRQ_EDGE_FALL) {
                    add_key(keymap[row][col]);
                }
            }
            else {
                if (dir == GPIO_IRQ_EDGE_RISE) {
                    remove_key(keymap[row][col]);
                }
            }
        }
        gpio_put(col_pins[col], 1);
    }

    // re-enable columns so interrupt works again
    for (uint8_t i = 0; i < COLS; i++) {
        gpio_put(col_pins[i], 0); 
    }

    clear_IRQ_flags();

    printf("matrix scanned (irq)\n");
}

void scan_matrix() {
    save_state();

    for (uint8_t col = 0; col < COLS; col++) {
        gpio_put(col_pins[col], 0);

        for (uint8_t row = 0; row < ROWS; row++) {
            if (gpio_get(row_pins[row]) == 0) {
                add_key(keymap[row][col]);
            }
            else {
                remove_key(keymap[row][col]);
            }
        }
        gpio_put(col_pins[col], 1);
    }

    printf("matrix scanned\n");
}

int main() {
    stdio_init_all();

    sleep_ms(5000);

    init_state();
    
    if (I2C_TOGGLE) {
        i2c_init(I2C_PORT, 400*1000);
        gpio_set_function(I2C_SDA, GPIO_FUNC_I2C);
        gpio_set_function(I2C_SCL, GPIO_FUNC_I2C);
        gpio_pull_up(I2C_SDA);
        gpio_pull_up(I2C_SCL);
    }

    irq_set_enabled(IO_IRQ_BANK0, true);

    printf("scanning\n");
    while (true) {
        if (state == CALC) {
            sleep_ms(50);
        }
        else if (state == NUMPAD) {
            scan_matrix();
            sleep_ms(50);
        }

        for (int i = 0; i < 6; i++) {
          printf("%d ", keys_pressed[i]);
        }
        printf("\n");
    }
}

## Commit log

2023-10-20 oh no please don't do this to yourself
    [Model C-1.0.kicad_pcb, Model C-1.0.kicad_sch]
2023-10-26 swap battery
    [Model C-1.0.kicad_pcb, Model C-1.0.kicad_sch]
2023-10-28 minor modifications
    [Model C-1.0.kicad_pcb]
2023-10-31 better pcb with the right components - maybe final?
    [Model C-1.0.kicad_pcb, Model C-1.0.kicad_sch]
2023-11-15 mounting holes + clean drc
    [Model C-1.0.kicad_pcb, Model C-1.0.kicad_sch]
2024-05-17 add license
    I have to add licenses to all of my repos bc people are stealing some of them and selling them (╥﹏╥)
2025-01-10 restarting project
    [Model C-1.0.kicad_pcb, Model C-1.0.kicad_sch]
2025-01-20 new pcb based on rp2040 - uses 8x 14 segment displays with mode switch - functionality extended to numpad + calculator w/ battery
    [model-c.kicad_pcb, model-c.kicad_sch]
2025-01-26 fixed power switch, mode button, updated readme, panelized, and added much better styling
    [model-c.kicad_pcb, model-c.kicad_sch, panel.kicad_pcb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]
2025-04-05 not working, but compiling
    [model-c-v1.0.c]
2025-04-06 getting scanning working in both interrupt and polling modes
2025-05-16 updating power system for automatic switching
    [model-c.kicad_sch]
2025-05-17 fixing battery charger from backfeeding, battery 3.3V regulation, 5V boost converter, and power multiplexing
    [model-c.kicad_sch]
2025-05-21 housing complete and PCB validated. need further validation and revisions of housing, as well as BOM to continue. updated PCB to rev. 2.1
    [14seg_surrogate.ipt, 2U Stabilizer.ipt, 6.25U Stabilizer.ipt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]
